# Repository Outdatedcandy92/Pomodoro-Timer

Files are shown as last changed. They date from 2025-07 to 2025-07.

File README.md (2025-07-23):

# Desk Pomodoro Timer

A low-powered, battery-operated desk timer designed to help you stay productive using the Pomodoro technique. This timer is powered by AA batteries and features a custom-built ATSAMD21-based board optimized for low power consumption and battery efficiency. It updates a 2.13-inch E-Ink display to show the timer and includes three mechanical switches for control.



## Features

- **Low Power Consumption**: Designed to run efficiently on AA batteries for extended periods.
- **Custom PCB**: Built around the ATSAMD21E18A microcontroller for low power and minimal passive components.
- **E-Ink Display**: A 2.13-inch E-Ink display for clear and power-efficient timer updates.
- **Mechanical Switches**: Three tactile mechanical switches for intuitive control.
- **Compact Design**: A sleek and functional case designed to fit on your desk.

## Files

- **PCB Design**: [src/pcb/](src/pcb/)
  - Includes schematics, Gerber files, and production-ready designs.
- **Case Design**: [src/production/](src/production/)
  - STL files for 3D printing the case.
- **Bill of Materials (BOM)**: [src/production/BOM_Board1_PCB1_2025-07-20.csv](src/production/BOM_Board1_PCB1_2025-07-20.csv)

## Images

### Schematic



### PCB



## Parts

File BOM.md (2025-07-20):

| Component | Quantity | Price |
| --- | --- | --- |
| PCB + Stencil | 1 | $13 |
| Parts | | $28 ($16+$12 shipping) |
| [Battery Holder](https://www.aliexpress.com/item/1005006225310014.html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) | 1 | $4 |
| [E-Ink Display](https://www.aliexpress.com/item/1005004644515880.html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) | 1 | $11 |
| [Switches](https://www.aliexpress.com/item/1005006255961111.html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) | 10 | $9 |
| [Keycap](https://www.aliexpress.com/item/1005006910173774.html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) | 10 | $5 |
| [SWD Dongle](https://www.aliexpress.com/item/1005008673124869.html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) | 1 | $5 |
| Total | | $75 |

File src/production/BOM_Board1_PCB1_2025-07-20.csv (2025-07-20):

No. | Quantity | Footprint | Value | Device | LCSC Stock | LCSC Price | JLCPCB Stock | JLCPCB Price
1 | 1 | USON-8_L3.0-W2.0-P0.50-BL-EP |  | W25Q16JVUXIQ |  |  | 52061 | 0.0708
2 | 1 | QFN-32_L5.0-W5.0-P0.50-TL-EP3.6 |  | ATSAMD21E18A-MUT |  |  | 893 | 0.9525
3 | 1 | C0402 | 1uF | CL05A105KA5NQNC |  |  | 7058167 | 0.0005
4 | 1 | R0402 | 10kΩ | 0402WGF1002TCE |  |  | 23584494 | 0.0001
5 | 1 | C0402 | 10uF | CL05A106MQ5NUNC |  |  | 3700674 | 0.0009
6 | 1 | C0805 | 22uF | CL21A226MAQNNNE |  |  | 6340754 | 0.0035
7 | 1 | R0402 | 36.5kΩ | AC0402FR-0736K5L |  |  | 9845 | 0.0002
8 | 1 | WSON-10_L2.5-W2.5-W0.50-TL-EP |  | TPS63900DSKR |  |  | 4221 | 0.1668
9 | 1 | IND-SMD_L4.5-W4.0_SLF0403-1 | 2.2uH | CY43-2.2UH |  |  | 10012 | 0.005
10 | 1 | Test-Point-0.5mm |  | Test-Point | 2290590 | 0.0061
11 | 1 | HDR-TH_7P-P2.54-V-M |  | HDR-M_2.54_1x7P | 2290590 | 0.0061
12 | 1 | R0402 | 5.1kΩ | 0402WGF5101TCE |  |  | 3396230 | 0.0001
13 | 1 | USB-TYPE-C-SMD_C9900008089 |  | USB-TYPE-C-017 |  |  | 1387 | 0.0183
14 | 1 | C0402 | 100nF | CL05B104KO5NNNC |  |  | 19603223 | 0.0002
15 | 1 | OSC-SMD_L3.2-W1.5 | 32.768kHz | X1A0001410003 |  |  | 3029 | 0.0317
16 | 1 | C0402 | 18pF | 0402CG180J500NT |  |  | 572738 | 0.0002

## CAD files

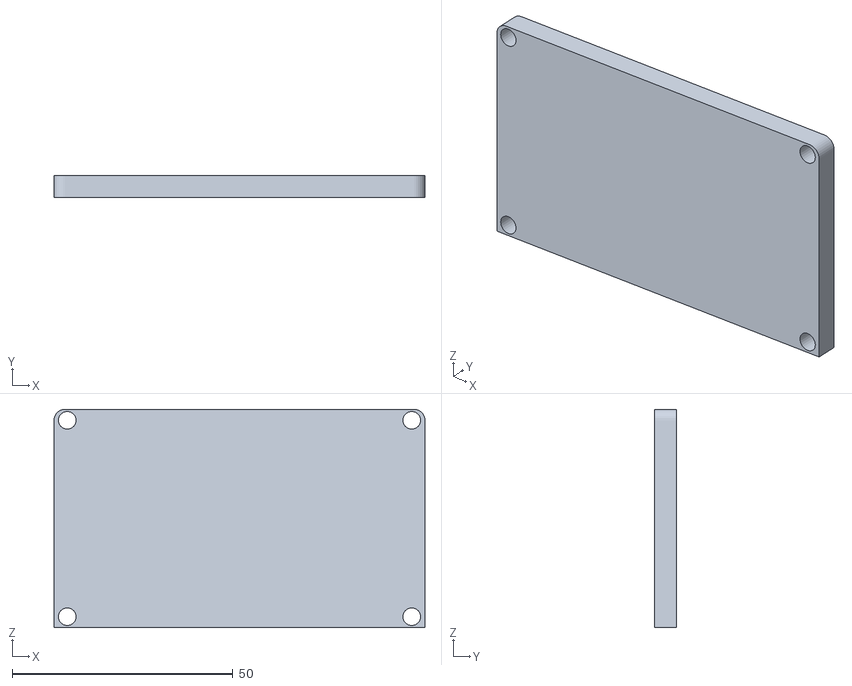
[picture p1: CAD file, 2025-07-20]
src/production/case_back.stl
84.0 x 5.00 x 49.5

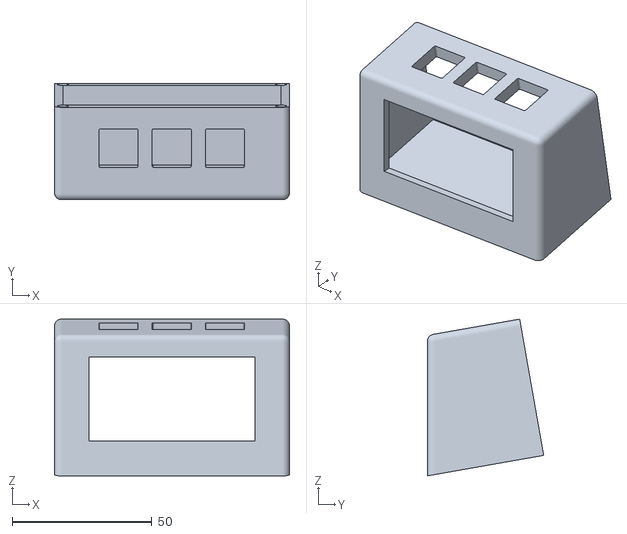
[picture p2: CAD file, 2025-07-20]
src/production/case_front.stl
84.0 x 41.6 x 56.1

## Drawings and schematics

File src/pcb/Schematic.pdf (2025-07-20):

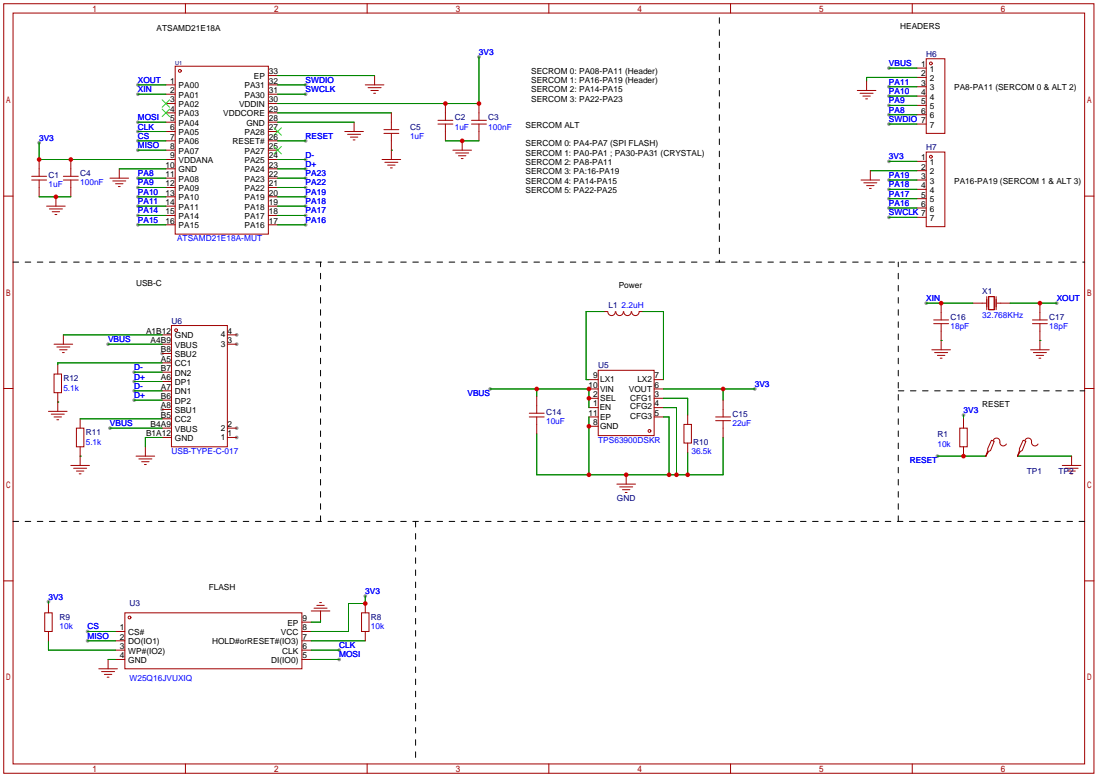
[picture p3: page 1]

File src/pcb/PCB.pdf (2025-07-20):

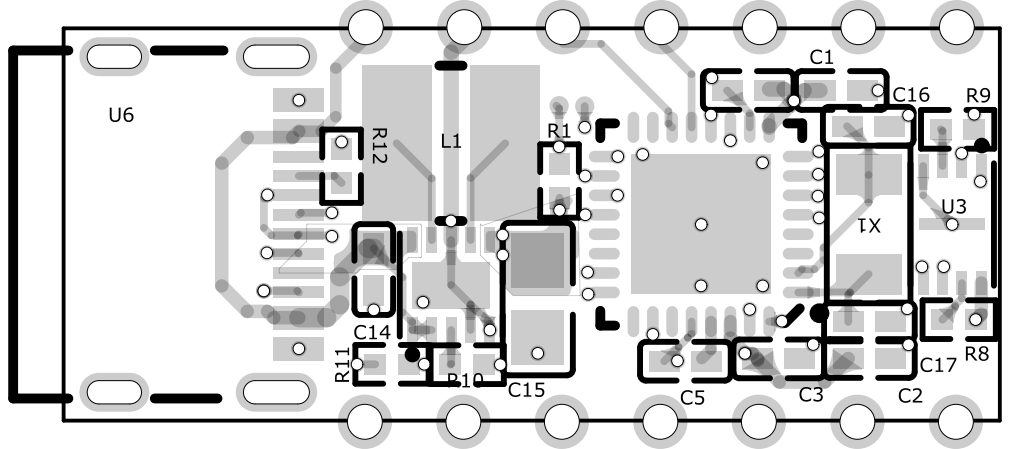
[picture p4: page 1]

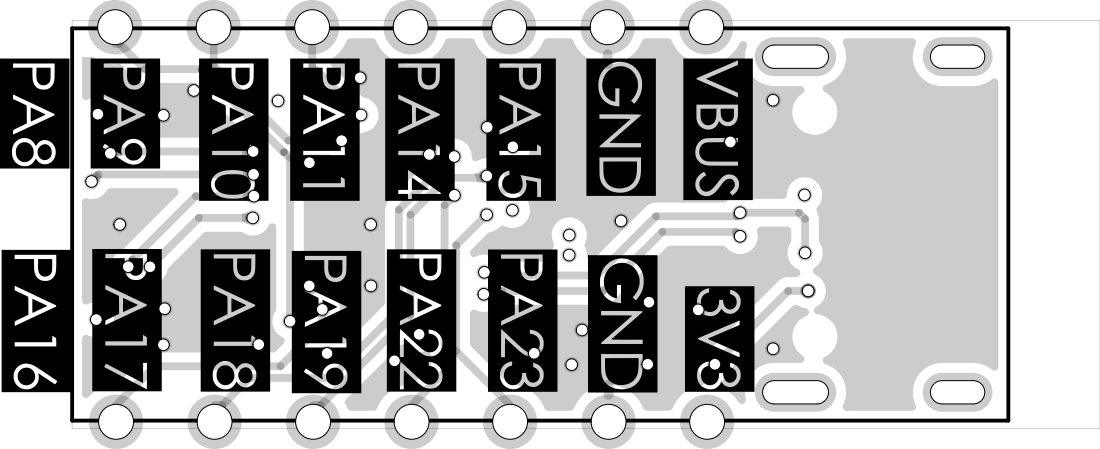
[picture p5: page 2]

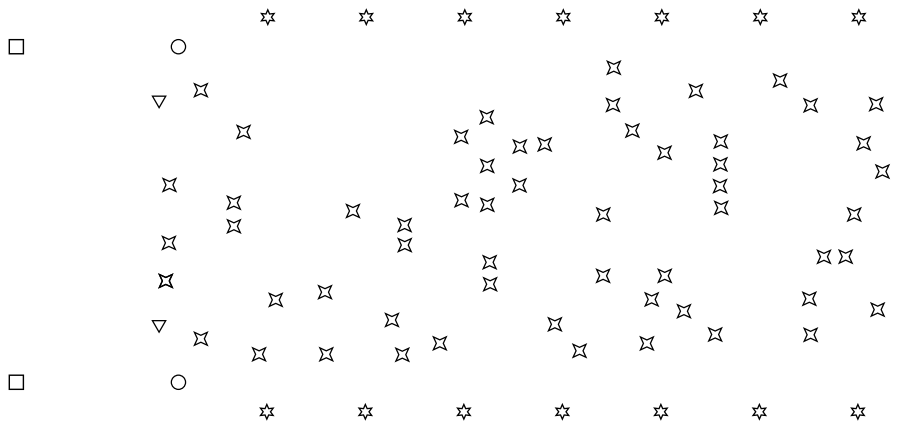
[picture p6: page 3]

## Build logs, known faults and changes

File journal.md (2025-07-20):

## What am I making?
I'm making a low powered, battery operated desk timer with mechanical switches on top for control and a 2.13 inch E-Ink display.

## Total Time Spent: 19 Hours

# Day 1 - 9th July

I need something very low powered for my project as its going to be running of AA batteries. I researched a lot and finally settled on an ESP32 chip as its very good for low current applications and deep sleep modes, and since I'm not going to use wifi the current consumption is even low. 
After a bit of research I decided to go with the ESP32-C3 chip, I looked at the datasheet and then used the schematics from it, also made a small and compact board for it.

*schematics*


*pcb*


Overall I did not like the board and I think I'll switch to a M0 based MCU for even lower power consumption

### Time Spent: 3 Hours

# Day 2 -10th July

After some research (chatgpt) I decided to use the ATSAMD21E18A as my new MCU.
Working with this was *kinda* weird, it dosen't have any traditional hardware design guide in sense. Had to scour the datasheet a lot for this board and look up reference designs.
It used a lot less passives compared to the ESP32 in order to work, all in all I think it was like 4 passive for the board to function (just decoupling capacitors). 
I did decide to opt in for an external 32k crystal for time keeping as the internal crystal is BAD.



### Time Spent: 6 Hours (i spent 5 hours 59 min reading the datasheet)
# Day 3 - 12th July

Finished routing the inital PCB, I unfortunately had to use 0.2mm vias because 0.3 were just not gonna work because it was such a small board, 0.2mm vias did add a HUGEEEE cost



decided to redo it with 0.3mm vias, routing was a bit difficult as I couldn't via in pad now.
But here is the finally result-



### Time Spent: 4 Hours
# Day 4 - 13th July

I posted the board in r/printedcircuitboard for a review, it turns out I was using the wrong inductor value, it had a really high dcr. I swapped it out for a better on and I also just decided to switch to using TPS63900 as its smaller and provides a good output current.




I also started on the 3D model for this project, I had to reverse engineer the 3D model for the e-ink display from the aliexpress drawings. After that I just put everything together, made a case, slanted the screen and boom thats it.




### Time Spent: 5 hours

# Day 5 - July 19

So I was working up on BOM today and turns out getting the board assembled is kinda expensive (about $50), I'm thinking it might be better if I just order the parts and assemble it myself, as right now im paying $21 just for the extended component fees.

I did think about using a adafruit m0 trinket but it only has 5 gpio pins so that just won't work for me :c

I updated my pcb design just a bit, I switched out my usb c connector to a more compact one.



### Time Spent: 1 hour
